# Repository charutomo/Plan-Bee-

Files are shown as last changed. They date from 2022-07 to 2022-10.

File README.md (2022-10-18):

# Plan-Bee-
**Hand crank Emergency Power Bank**

**Welcome!** :wave:

## Introduction
<h3 align="center">Plan Bee</h3>
<div align="center">
  <a href="https://github.com/charutomo/Plan-Bee-">
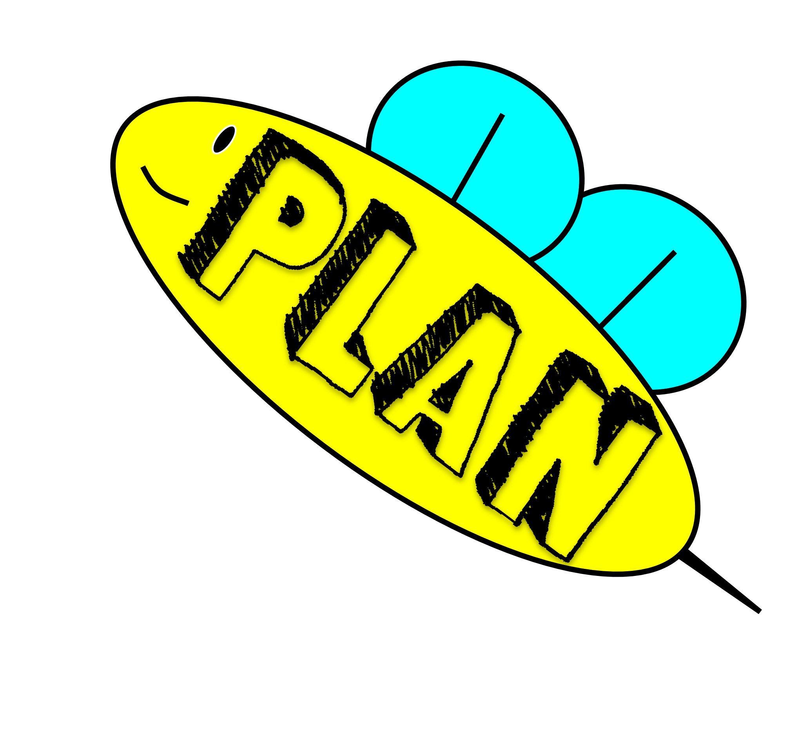
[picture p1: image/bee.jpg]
bee
    
  </a>
</div>

[Andy](https://github.com/Andypek921), Jia Woei, [Jinghui](https://github.com/jhlow5), 
[Chermaine](https://github.com/chermainegoh) and [Charissa](https://github.com/charutomo) 
are part of Plan Bee and we are making a prototype of an emergency hand crank power bank 
in fulfilment of the course PS5888: Making and Tinkering. In this particular repository, 
it would consists the C & C++ codes of our functions in our power bank
for Arduino Uno and ESP32-WROOM-32D respectively. More Information can be found in our [blog](https://blogs.ntu.edu.sg/ps5888-2022-g11/).

<br>

## Content Of Repository 
Listed below are the current codes for `Plan Bee `: 

### Hyperlinks to the respective folders
Click to view the table of content
<br>
<details>
	<summary>Table of Content</summary>

* [README.MD](https://github.com/charutomo/Plan-Bee-/blob/main/README.md)

* [License](https://github.com/charutomo/Plan-Bee-/blob/main/LICENSE)

* [Arduino Uno](https://github.com/charutomo/Plan-Bee-/blob/main/for%20Arduino)
	* [LED](https://github.com/charutomo/Plan-Bee-/blob/main/for%20Arduino/LED/LED.ino)

	* [Current, Voltage and Power Monitor](https://github.com/charutomo/Plan-Bee-/blob/main/for%20Arduino/INA3221_for_arduino_testing/INA3221_for_arduino_testing.ino)

* [ESP32-WROOM-32D](https://github.com/charutomo/Plan-Bee-/blob/main/for%20ESP32)
	* [for ILI9341](https://github.com/charutomo/Plan-Bee-/blob/main/for%20ESP32/for%20ILI9341)

	* [for SSH1106](https://github.com/charutomo/Plan-Bee-/blob/main/for%20ESP32/for%20SH1106/SH1106)
	
	* [for SSD1306](https://github.com/charutomo/Plan-Bee-/blob/main/for%20ESP32/for%20SSD1306/INA3221_works)

* [Modified Libraries](https://github.com/charutomo/Plan-Bee-/tree/main/modified%20libraries)
	* [Adafruit_ILI9341](https://github.com/charutomo/Plan-Bee-/tree/main/modified%20libraries/Adafruit_ILI9341)

	* [TFT_eSPI](https://github.com/charutomo/Plan-Bee-/tree/main/modified%20libraries/TFT_eSPI)

* [image](https://github.com/charutomo/Plan-Bee-/blob/main/image)

</details>

### Structure of repository

The structure of `Plan Bee ` repository is as such:

```
Plan Bee 
│	README.md
│	LICENSE
│
├───	PCB Design
│	├─── PCB Main V1
│	├─── PCB Main V2
│	└─── PCB Main V3
│
├───	For Arduino
│	├─── INA226 for arduino uno
│	├─── INA3221 for arduino uno
│	├─── LED
│	└─── Voltage and Current sensor using ACS712 and potentiometer
│
├─── For ESP32
│	├─── for ILI9341
│	│    ├─── ILI9341_INA226
│	│    ├─── ILI9341_INA3221
│	│    ├─── graphictestILI9341
│	│    ├─── printextILI9341
│	│    └─── README.md
│	│
│	├─── for SH1106
│	│    ├─── SH1106 (using INA3221 and general use)
│	│    ├─── SH1106_forUsers (using INA3221 and for users)
│	│    └─── README.md
│	│
│	├─── for SSD1306
│	│    └───  INA3221_works
│	│
│	└─── intermediate
│	     ├─── Temperature
│	     └─── switch
│
├─── image
│	├─── Plan Bee Logo (ALIVE).png
│	├─── Plan Bee Logo (DEAD).png
│	├─── bee.jpg
│	└─── pinout.jpg
│
├─── modified libraries
│	├─── Adafruit_ILI9341
│	└─── TFT_eSPI
│

```

<br>

## Libraries
These are libraries imported:

### Current and Voltage Sensor
* [BeastDevices INA3221](https://github.com/beast-devices/Arduino-INA3221)
* [INA226_WE](https://github.com/wollewald/INA226_WE)

### Display Screen
* [Adafruit SSD1306](https://github.com/adafruit/Adafruit_SSD1306)
* [Adafruit ILI9341](https://github.com/adafruit/Adafruit_ILI9341)
* [TFT_eSPI](https://github.com/Bodmer/TFT_eSPI)
* [ESP32-SH1106-OLED](https://github.com/nhatuan84/esp32-sh1106-oled)
* [Modified Libraries](https://github.com/charutomo/Plan-Bee-/tree/main/modified%20libraries/)

### Datetime
* [NTPClient](https://github.com/barsrb/NTPClient)
* [ESP32Time](https://github.com/fbiego/ESP32Time)

### Temperature Sensor
* [DallasTemperature](https://github.com/vlast3k/Arduino-libraries/tree/master/DallasTemperature)

### Encoder
* [Ai Esp32 Rotary Encoder](https://github.com/igorantolic/ai-esp32-rotary-encoder)

<br>

## Components
Currently, we use the following items for the functions: 
|Items			| Model No. 1	| Model No. 2 | Model No. 3|
| :---:	|:---:	 	|:---: |:---:  |
|Current, Voltage Sensor| INA3221	 	| INA226	  | -		 |
|Display Screen		| SSD1306	 	| SSH1106	  | ILI9341	 |
|Temperature Sensor	| DS18B20	 	|	-	  |	-	 |
|Encoder			| HW040	 	|	-	  |	-	 |
|Relay			|SRD-05VDC-SL-C	| 	-	  |	-	 |
|Button			|Tactile Push Button|	-	  |	-	 |

<br>

## Getting started

1. Clone this repository into your working station, key in the following command in CMD(Windows) or Terminal(Mac or Linux). 

For Windows/Mac, to save the repository content into a folder in Desktop: 

```
cd Desktop
```

Followed by 

```
git clone https://github.com/charutomo/Plan-Bee-
```

For Linux, to save the repository content into a folder in Desktop: 

```
$ ls Desktop
```

Followed by 

```
$ git clone https://github.com/charutomo/Plan-Bee-
```

2. Install Arduino IDE(if you haven't) and download the [libraries](#libraries) to have the full features.

3. You can start upload code from the repository to test out.

<br>

## Acknowledgement
Special thanks to Tony and Qi Jie for their guidance throughout the whole project of `Plan Bee`.

<br>

## Further enquiries
Please direct your enquiries to planbee9555@gmail.com or under the issues section.

<br>

Thank you for your support! :blush:

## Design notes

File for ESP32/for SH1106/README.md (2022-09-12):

# ESP32 Pinout connected to SSH1106
<br/>

## Pinout
<h3 align="center">Pinout For ESP32-WROOM-32D</h3>
<div align="center">
  <a href="https://github.com/charutomo/Plan-Bee-">
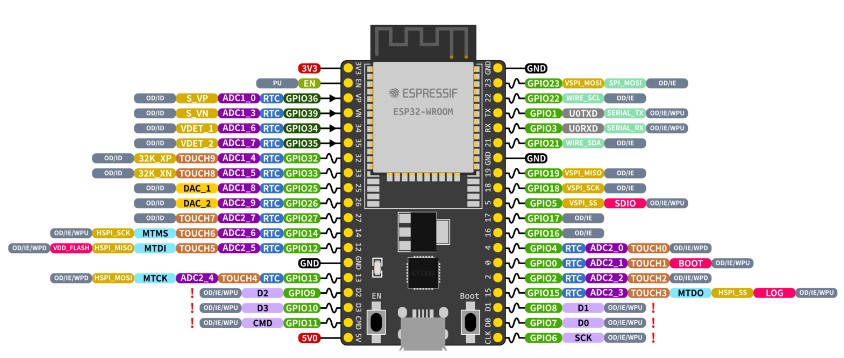
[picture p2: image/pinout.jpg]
pinout
    
  </a>
</div>
Above shows the pinout of ESP32-WROOM-32D.
<br/>

## List of Pins
Listed below are the current pins occupied for `Plan Bee`: 
<br/>
SSH1106
<br/>
|SSH1106		|Type of Pin on ESP32 	|
|:---:|:---:	 	|
|GND		|GND 		|
|VCC		|3v3	 	 |
|SCL		|22	 		|
|SDA		|21			|
<br/>
This is for the 1.3 inch ILI9341 Display.
<br/>
<br/>

Temperature Sensor DS18B20
<br/>
|DS18B20		|Type of Pin on ESP32 |
| :---:	|:---:		 	|
|VCC			|5V	 	 	 |
|DQ			|0		 		 |
|GND			|GND 		 	|
<br/>

INA3221 Current and Voltage Sensor
<br/>
|INA3221		|Type of Pin on ESP32 |
| :---:|:---:		 |
|VCC			|3v3	 	 |
|GND			|GND 		 |
|SCL			|22	 		 |
|SDA			|21			 |
<br/>

INA226 Current and Voltage Sensor
<br/>
|INA226		|Type of Pin on ESP32 |
| :---:|:---:		 |
|VCC			|3v3	 	 |
|GND			|GND 		 |
|SDA			|22	 		 |
|SCL			|21			 |
|ALERT			|25			 |
<br/>

Button
<br/>
|Button		|Type of Pin on ESP32 |
| :---:|:---:		 |
|VCC					|3v3	 	 |
|Digital Pin			|4 		 |
<br/>

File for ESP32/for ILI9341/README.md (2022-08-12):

# ESP32 Pinout for Plan Bee

## Pinout
<h3 align="center">Plan Bee</h3>
<div align="center">
  <a href="https://github.com/charutomo/Plan-Bee-">
    pinout
  </a>
</div>
Above shows the pinout of ESP32-WROOM-32D.

## List of Pins
Listed below are the current pins occupied for `Plan Bee`: 

### ILI9341 Display
|ILI9341 Display	|Type of Pin on ESP32 |
| :---:	|:---:		 |
|MISO			|12	 	 |
|LED			|3v3		 |
|SCK			|32	 		 |
|MOSI			|33			 |
|DC			|26	 		 |
|RESET		|25			 |
|CS			|27			 |
|GND			|GND 		 |
|VCC			|3v3	 	 |

This is for the 2.4 inch ILI9341 Display.

### SSH1106
|SSH1106		|Type of Pin on ESP32 	|
|:---:|:---:	 	|
|GND		|GND 		|
|VCC		|3v3	 	 |
|SCL		|22	 		|
|SDA		|21			|

This is for the 1.3 inch ILI9341 Display.

### SSD1306
|SSD1306		|Type of Pin on ESP32	 |
|:---:	|:---:	 	 |
|GND		|GND 		 |
|VCC		|3v3	 	 |
|D0		|32	 		 |
|D1		|33			 |
|RESET	|25		 	 |
|DC		|26			 |
|CS		|27			 |

This is for the 0.96 inch ILI9341 Display.

### Temperature Sensor DS18B20
|DS18B20		|Type of Pin on ESP32 |
| :---:	|:---:	 |
|VCC			|5V	 	 |
|DQ			|0	 |
|GND			|GND 	 |

### INA3221 Current and Voltage Sensor
|INA3221		|Type of Pin on ESP32 |
| :---:|:---:		 |
|VCC			|3v3	 	 |
|GND			|GND 		 |
|SCL			|22	 		 |
|SDA			|21			 |

### INA226 Current and Voltage Sensor
|INA226		|Type of Pin on ESP32 |
| :---:	|:---:		 |
|VCC			|3v3	 	 |
|GND			|GND 		 |
|SDA			|21			 |
|SCL			|22	 		 |
|ALERT		|25 *intercept	 |

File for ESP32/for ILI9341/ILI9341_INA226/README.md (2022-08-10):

# ESP32 Pinout connected to ILI9341 & INA226
<br/>

## Pinout
<h3 align="center">Pinout For ESP32-WROOM-32D</h3>
<div align="center">
  <a href="https://github.com/charutomo/Plan-Bee-">
    pinout
  </a>
</div>
Above shows the pinout of ESP32-WROOM-32D.
<br/>

## List of Pins
Listed below are the current pins occupied for `Plan Bee`: 
<br/>
ILI9341 Display
<br/>
|ILI9341 Display	|Type of Pin on ESP32 |
| :---:	|:---:		 |
|MISO			|12	 	 |
|LED			|3v3		 |
|SCK			|32	 		 |
|MOSI			|33			 |
|DC			|26	 		 |
|RESET		|25			 |
|CS			|27			 |
|GND			|GND 		 |
|VCC			|3v3	 	 |
<br/>
This is for the 2.4 inch ILI9341 Display.
<br/>
<br/>

Temperature Sensor DS18B20
<br/>
|DS18B20		|Type of Pin on ESP32 |
| :---:	|:---:		 	|
|VCC			|5V	 	 	 |
|DQ			|0		 		 |
|GND			|GND 		 	|
<br/>

INA226 Current and Voltage Sensor
<br/>
|INA226		|Type of Pin on ESP32 |
| :---:|:---:		 |
|VCC			|3v3	 	 |
|GND			|GND 		 |
|SDA			|21	 		 |
|SCL			|22			 |
|ALERT			|18			 |
<br/>

SRD-05VDC-SL-C Relay
<br/>
|SRD-05VDC-SL-C		|Type of Pin on ESP32 |
| :---:	|:---:		 |
|VCC				|3v3	 	 |
|IN1				|2			 |
|GND				|GND 		 |
<br/>

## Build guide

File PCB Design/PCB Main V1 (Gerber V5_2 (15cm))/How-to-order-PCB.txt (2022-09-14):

How to Order PCB

Please refer to:
https://docs.easyeda.com/en/PCB/Order-PCB

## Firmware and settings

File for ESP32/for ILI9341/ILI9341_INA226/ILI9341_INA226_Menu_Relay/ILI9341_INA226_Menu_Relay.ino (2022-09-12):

#include "SPI.h"
#include "Adafruit_ILI9341.h"
#include "Bee.h"
#include "AiEsp32RotaryEncoder.h"
#include "Arduino.h"
#include <Wire.h>
#include <INA226_WE.h>
#include <SPI.h>
#include <DallasTemperature.h>

#define TFT_CLK    32 
#define TFT_MOSI   33
#define TFT_MISO   12 
#define TFT_CS     27 
#define TFT_DC     26 
#define TFT_RST    25 
#define PRINT_DEC_POINTS  3  
#define SENSOR_PIN  0 
#define ROTARY_ENCODER_A_PIN 14
#define ROTARY_ENCODER_B_PIN 17
#define ROTARY_ENCODER_BUTTON_PIN 16
#define ROTARY_ENCODER_VCC_PIN - 1 
#define ROTARY_ENCODER_STEPS 4
#define RELAY_PIN1 2

float tempC; 
float tempF;
float shuntVoltage_mV = 0.0;
float loadVoltage_V = 0.0;
float busVoltage_V = 0.0;
float current_mA = 0.0;
float power_mW = 0.0; 
int menu_state = 0;
int value = 0;
int batt = 0;
int temp = 1;
int cred = 1;
int tech = 1;
float voltage[2];
bool active_state = false;

OneWire oneWire(SENSOR_PIN);
DallasTemperature DS18B20(&oneWire);
Adafruit_ILI9341 tft = Adafruit_ILI9341(TFT_CS, TFT_DC, TFT_MOSI, TFT_CLK, TFT_RST, TFT_MISO);
AiEsp32RotaryEncoder rotaryEncoder = AiEsp32RotaryEncoder(ROTARY_ENCODER_A_PIN, ROTARY_ENCODER_B_PIN, ROTARY_ENCODER_BUTTON_PIN, ROTARY_ENCODER_VCC_PIN, ROTARY_ENCODER_STEPS);
INA226_WE ina226batt = INA226_WE(0x40); 

void IRAM_ATTR readEncoderISR() {
  rotaryEncoder.readEncoder_ISR();
}

void setup() {
  //initialize rotary encoder
  rotaryEncoder.begin();
  rotaryEncoder.setup(readEncoderISR);
  //set boundaries and if values should cycle or not
  //in this example we will set possible values between 0 and 1000;
  bool circleValues = false;
  rotaryEncoder.setBoundaries(0, 1000, circleValues); //minValue, maxValue, circleValues true|false (when max go to min and vice versa)
  rotaryEncoder.setAcceleration(250); 

  //initalise digital pin as an output
  pinMode(RELAY_PIN1, OUTPUT);

  Serial.begin(115200);
  
  tft.begin();
  DS18B20.begin();
  Wire.begin();
  tft.fillScreen(ILI9341_BLACK);
  tft.setRotation(0);
  tft.drawRGBBitmap(0, 0, Plan_Bee_Logo_ALIVE, BEE_WIDTH,BEE_HEIGHT);
  delay(1000);
  
  ina226batt.init();
  ina226batt.setAverage(AVERAGE_128); 
  ina226batt.setConversionTime(CONV_TIME_8244); 
  ina226batt.setMeasureMode(TRIGGERED); 
  ina226batt.setCurrentRange(MA_800); 
  ina226batt.setCorrectionFactor(0.72); 
  menu();

  Serial.println(active_state);
}

void loop() {
  if (active_state == true){
    if (rotaryEncoder.encoderChanged() && menu_state < 5) {
      value = rotaryEncoder.readEncoder();
      Serial.println(value);
      if (value % 4 == 0) {
        menu_state = 1;
        batt = 1;
      } else if (value % 4 == 1) {
        menu_state = 2;
        temp = 1;
      } else if (value % 4 == 2) {
        menu_state = 3;
        cred = 1;
      }
      else if (value % 4 == 3) {
        menu_state = 4;
        tech = 1;
      }
      changemenu();
    }
    if (rotaryEncoder.isEncoderButtonClicked()) {
      if (menu_state >= 5){
        menu_state = 0;
      } else if (value % 4 == 0) { 
        menu_state = 7;
      } else if (value % 4 == 1) {
        menu_state = 8;
      } else if (value % 4 == 2) {
        menu_state = 9;
      } 
      else if (value % 4 == 3) {
        menu_state = 10;
      } 
      changemenu();
    }
    if (menu_state>5){
      changemenu();
      delay(1000);
    }
  }   
  else if(active_state == false){
    for (int i = 0; i < 7000; i++){ 
      //Serial.println(i);
      if (rotaryEncoder.isEncoderButtonClicked()) {
        active_state = true;
        menu1();
      }
    }
    Serial.println(active_state);
    Serial.print("Start: ");
    Serial.println(millis());
    ina226batt.startSingleMeasurement();
    ina226batt.readAndClearFlags();
    voltage[0] = ina226batt.getBusVoltage_V(); 
    relay(voltage[0]);
    Serial.println(voltage[0]);
    Serial.print("End: ");
    Serial.println(millis());
  }
}

void changemenu() {
  /* Menu values
  0: main menu without any selector
  1: main menu with selector on Battery Info
  2: main menu with selector on Temperature
  3: main menu with selector on Credits
  4: main menu with selector on Tech Support

  7: Battery Info Page
  8: Temperature Page 
  9: Credits Page
  10: Tech Support Page
  */
  switch (menu_state) {
  case 0:
    menu();
    break;
  case 1:
    menu1();
    break;
  case 2:
    menu2();
    break;
  case 3:
    menu3();
    break;
  case 4:
    menu4();
    break;
  case 7:
    showbattery();
    break;
  case 8:
    showtemp();
    break;
  case 9:
    credits();
    break;
  case 10:
    techsupport();
    break;
  }
}

// menu with no selector
void menu() {
  tft.fillScreen(ILI9341_BLACK);
  tft.setRotation(0);
  tft.setTextSize(2);
  tft.setTextColor(ILI9341_YELLOW);
  tft.setCursor(70, 40);
  tft.println("Battery Info");
  tft.setCursor(70, 70);
  tft.println("Temperature");
  tft.setCursor(70, 100);
  tft.println("Credits");
  tft.setCursor(70, 130);
  tft.println("Tech Support");
  active_state = false;
  Serial.println("false");
}

// menu with selector on 1
void menu1() {
  tft.fillRect(40,40,30,130, ILI9341_BLACK);
  tft.setCursor(40, 40);
  tft.print("->");
}

// menu with selector on 2
void menu2() {
  tft.fillRect(40,40,30,130, ILI9341_BLACK);
  tft.setCursor(40, 70);
  tft.print("->");
}

// menu with selector on 3
void menu3() {
  tft.fillRect(40,40,30,130, ILI9341_BLACK);
  tft.setCursor(40, 100);
  tft.print("->");
}

// menu with selector on 4
void menu4(){
  tft.fillRect(40,40,30,130, ILI9341_BLACK);
  tft.setCursor(40, 130);
  tft.print("->");
}

// show the battery value
void showbattery(void) {
  if (batt ==1){
    refreshorig();
    batt = 0;
  }
  else {
    refreshbatt();
  }
  float current[2]; //no. of channels
  float voltage[2];
  ina226batt.startSingleMeasurement();
  ina226batt.readAndClearFlags();
  current[0] = ina226batt.getCurrent_mA();
  voltage[0] = ina226batt.getBusVoltage_V();
  float power0 = ina226batt.getBusPower();
  float battpercent = ((voltage[0]-3.4)/(4.2-3.4))*100;
  offsettext(0,3);
  tft.println("Battery");
  offsettext(40,2);
  tft.print("Current:");
  tft.println(current[0], PRINT_DEC_POINTS);
  offsetunits(40,2);
  tft.print("mA, ");
  offsettext(70,2);
  tft.print("Voltage:");
  tft.println(voltage[0], PRINT_DEC_POINTS);
  offsetunits(70,2);
  tft.print("V, ");
  offsettext(100,2);
  tft.print("Power: "); 
  tft.println(power0);
  offsetunits(100,2);
  tft.print("mW");
  offsettext(130,2);
  tft.println("Battery Percentage:");
  offsettext(160,2);
  tft.print(battpercent);
  offsetunits(160,2);
  tft.println("%");
}

// show the temperature
void showtemp(void) {
  if (temp ==1){
    refreshorig();
    temp = 0;
  }
  else{
    refreshtemp();
  }
  offsettext(0,3);
  tft.println("Temperature");
  tft.println();
  DS18B20.requestTemperatures();       
  tempC = DS18B20.getTempCByIndex(0);  
  tempF = tempC * 9 / 5 + 32;
  offsetdegrees(30);
  offsettext(40,2);
  tft.print(tempC);
  tft.println(" C");
  offsetdegrees(60);
  offsettext(70,2);
  tft.print(tempF);
  tft.println(" F");

  delay(1000);
}

// show the credits
void credits(void) {
  if (cred == 1){
    refreshorig();
    cred = 0;
  }
  offsettext(0,3);
  tft.println("Credits");
  tft.println();
  offsettext(30,2);
  tft.println("Group Members:");
  offsettext(60,2);
  tft.println("Andy,Jia Woei,Jing Hui,");
  offsettext(90,2);
  tft.println("Chermaine and Charissa");
  tft.println();
  offsettext(120,2);
  tft.println("With thanks to Tony");
  offsettext(150,2);
  tft.println("and Qi Jie");

  delay(1000);
}

//show tech support information
void techsupport(void){
  if (tech == 1){
    refreshorig();
    tech = 0;
  }
  offsettext(0,3);
  tft.println("Tech Support");
  offsettext(40,2);
  tft.println("Email Address:");
  offsettext(70,2);
  tft.println("planbee9555@gmail.com");

  delay(1000);
}

void offsettext(int y, int font){
  /*
   * Function: offsetdegree
   * ----------------
   * Set cursor to (40,y) which indent the screen and set text size accordingly to the input font
   * 
   * y: y-axis value to be input for printing text
   * font: font size of the text to be printed on display
   */
  tft.setCursor(40, y);
  tft.setTextColor(ILI9341_YELLOW);
  tft.setTextSize(font);
}

void offsetdegrees(int y){
  /*
   * Function: offsetdegrees
   * ----------------
   * Set cursor and indent the screen to show the degree symbol
   * 
   * y: y-axis value to be input for the degrees symbol
   * 
   */
  tft.setCursor(100, y);
  tft.setTextColor(ILI9341_YELLOW);
  tft.setTextSize(1);
  tft.println("o");
}

void offsetunits(int y, int font){
  /*
   * Function: offsetunits
   * ----------------
   * Set cursor and indent the units to x = 240
   * 
   * y: y-axis value to be input for the units symbol
   * font: font size of the text to be printed on display
   * 
   */
   tft.setCursor(240, y);
   tft.setTextColor(ILI9341_YELLOW);
   tft.setTextSize(font);
   
}

void refreshorig(void){
  /*
   * Function: refreshorig
   * ----------------
   * Fills a blackbox space to cover the menu screen for refreshing page 
   * 
   */
  tft.fillRect(40,40,200,120,ILI9341_BLACK);
}

void refreshbatt(void){
  /*
   * Function: refreshbatt
   * ----------------
   * Fills a blackbox space to cover the old battery values
   * for refreshing page on battery screen before showing new values
   * 
   */
  tft.fillRect(135,40,80,60,ILI9341_BLACK);
  tft.fillRect(110,100,100,20,ILI9341_BLACK);
  tft.fillRect(40,160,90,30,ILI9341_BLACK);
}

void refreshtemp(void){
  /*
   * Function: refreshtemp
   * ----------------
   * Fills a blackbox space to cover the old temperature values for refreshing page
   * on temperature screen before showing new values
   * 
   */
  tft.fillRect(40,30,60,80,ILI9341_BLACK);
}

void relay(float avgvolt) {
  /*
   * Function: relay
   * ----------------
   * Activates relay with normally closed mode .
   * If any given voltage of battery is above 4.2 volts, it switches off to prevent overcharging of the battery.
   * Otherwise, it will continuously be on.
   * 
   */
  if (avgvolt >= 4.2) {
    digitalWrite(RELAY_PIN1, HIGH); 
  }
  else {
    digitalWrite(RELAY_PIN1, LOW);
  }
}

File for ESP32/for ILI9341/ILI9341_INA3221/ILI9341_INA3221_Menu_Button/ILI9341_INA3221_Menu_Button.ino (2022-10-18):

#include "SPI.h"
#include <TFT_eSPI.h>
#include "Arduino.h"
#include "Bee.h"
#include <Wire.h>
#include <Beastdevices_INA3221.h>
#include <SPI.h>
#include <OneWire.h>
#include <DallasTemperature.h>
#include <WiFi.h>
#include <NTPClient.h>
#include <WiFiUdp.h>
#include <ESP32Time.h>

#define TFT_SCLK 32
#define TFT_MOSI 33
#define TFT_MISO 12
#define TFT_CS   27
#define TFT_DC 26
#define TFT_RST 25
#define PRINT_DEC_POINTS  3  
#define SENSOR_PIN  0
#define BUTTON_PIN 4 // GPIO4 pin connected to button
//#define TFT_WIDTH 240
//#define TFT_HEIGHT  320

float current1;
float voltage1;
float power1;
float battery1;
float energy1;
float current2;
float voltage2;
float power2;
float energy3;
float current3;
float voltage3;
float power3;
float energy2;
float tempC; 
float tempF;
float currentarray1[10];
float voltagearray1[10];
float powerarray1[10];
float currentarray2[10];
float voltagearray2[10];
float powerarray2[10];
float currentarray3[10];
float voltagearray3[10];
float powerarray3[10];
int clicknum;
int lastState = HIGH;
int currentState;
int batt = 1;
int temp = 1;
int cred = 1;
int tech = 1;
int cust = 1;
int numloop = 0;
unsigned long drawTime = 0;
// Replace with your network credentials
const char* ssid     = "SSID";
const char* password = "Password";
char *dayarray[]= {"Monday", "Tuesday", "Wednesday", "Thursday", "Friday", "Saturday", "Sunday"};

Beastdevices_INA3221 ina3221(INA3221_ADDR40_GND); 

OneWire oneWire(SENSOR_PIN);
DallasTemperature DS18B20(&oneWire);
TFT_eSPI tft = TFT_eSPI(); 
WiFiUDP ntpUDP;
NTPClient timeClient(ntpUDP);
ESP32Time rtc(0);

void setup() {
  Serial.begin(115200);
  
  // initialise the screen
  tft.begin();
  tft.fillScreen(ILI9341_WHITE);
  tft.setFreeFont(FF33);
  DS18B20.begin();

  //draw the bee logo
  int x = random(tft.width()  - BEE_WIDTH);
  int y = random(tft.height() - BEE_HEIGHT);
  //using the drawXBitmap function, bee_logo is in the header folder, Bee.h
  tft.drawXBitmap(x, y, bee_logo, BEE_WIDTH,BEE_HEIGHT,TFT_BLACK,TFT_WHITE); // monochrome, white background
  delay(1000);

  // initialise the NTPClient
  //wifiConnect();
  //custom page ro show the name of the owner of the power bank and datetime
  rtc.setTime(00, 40, 16, 18, 10, 2022);
  
  // initialise INA3221
  ina3221.begin();
  ina3221.reset();
  ina3221.setShuntRes(100, 100, 100);
  tft.fillScreen(ILI9341_BLACK);

}

void loop() {
  currentState = digitalRead(BUTTON_PIN);
  int index = clicknum%7;
  ifClick();
  Serial.println(currentState);
  switch(index){
    case 0:
      showcustom();
      break;
    case 1:
      showbattery();
      break;
    case 2:
      showinput();
      break;
    case 3:
      showoutput();
      break;
    case 4:
      showtemp();
      break;
    case 5:
      credits();
      break;
    case 6:
      techsupport();
      break;
    
  }
  lastState = currentState;
}

void ifClick(void){
 if (lastState == LOW && currentState == HIGH){
    clicknum++;
    cred = 1;
    tech = 1;
    batt = 1;
    temp = 1;
    cust = 1;
    Serial.print(clicknum);
    }
}

void wifiConnect(void){
  Serial.print("Connecting to ");
  Serial.println(ssid);
  WiFi.begin(ssid, password);
  while (WiFi.status() != WL_CONNECTED) {
    delay(500);
    Serial.print(".");
  }
  // Print local IP address and start web server
  Serial.println("");
  Serial.println("WiFi connected.");
  Serial.println("IP address: ");
  Serial.println(WiFi.localIP());

  // Initialize a NTPClient to get time
//  timeClient.begin();
  // Set offset time in seconds to adjust for your timezone, for example:
  // GMT +1 = 3600
  // GMT +8 = 28800
  // GMT -1 = -3600
  // GMT 0 = 0
//  timeClient.setTimeOffset(0); 
}

void showcustom(void){
  if (cust ==1){
    tft.fillScreen(ILI9341_BLACK);
    cust = 0;
  }
  offsettext(40);
  tft.println("Hello Name!");  

  //using library ESP32Time
  offsettext(120);
  tft.setTextPadding(100);
  tft.print(rtc.getDate(true));
  
  offsettext(150);
  tft.print("Time Now - ");
  tft.setTextPadding(100);
  tft.drawString(rtc.getTime(),160,137);

  //for NTPClient
//  while(!timeClient.update()) {
//    timeClient.forceUpdate();
//  }
//
//  offsettext(120);
//  tft.print("Date - ");
//  tft.print(timeClient.getDay());
//  tft.print(" / ");
//  tft.print(timeClient.getMonth());
//  tft.print(" / ");
//  tft.print(timeClient.getYear());
//  
//  offsettext(150);
//  tft.print("Day - ");
//  tft.print(dayarray[timeClient.getDayOfWeek()-1]);
//  
//  offsettext(180);
//  tft.print("Time Now - ");
//  tft.print(timeClient.getFormattedTime());
}

// show the battery value
void showbattery(void) {
  if (batt ==1){
    tft.fillScreen(ILI9341_BLACK);
    batt = 0;
  }
  int index = numloop%10;
  currentarray1[index] = ina3221.getCurrent(INA3221_CH1);
  voltagearray1[index] = ina3221.getVoltage(INA3221_CH1);
  numloop++;
  if (numloop<10){
      current1 = avgvalue(currentarray1,numloop);
      voltage1 = avgvalue(voltagearray1,numloop);
      power1 = avgvalue(powerarr(currentarray1,voltagearray1),numloop);
      energy1 = energy(powerarr(currentarray1,voltagearray1));
      battery1 = battpercent(avgvalue(voltagearray1,numloop));
  }
  else{
      current1 = avgvalue(currentarray1,10);
      voltage1 = avgvalue(voltagearray1,10);
      power1 = avgvalue(powerarr(currentarray1,voltagearray1),10);
      energy1 = energy(powerarr(currentarray1,voltagearray1));
      battery1 = battpercent(avgvalue(voltagearray1,10));
  }
  if (numloop%10 == 0){
    tft.setRotation(0);
    offsettext(20);
    tft.println("Battery");
    
    offsettext(60);
    tft.print("Current:");
    tft.setTextPadding(100);
    tft.drawFloat(current1, 3, 150, 47);
    tft.setCursor(230, 60);
    tft.println("A");
    
    offsettext(100);
    tft.print("Voltage:");
    tft.setTextPadding(100);
    tft.drawFloat(voltage1, 3, 150, 83);
    tft.setCursor(230, 100);
    tft.print("V");
    
    offsettext(140);
    tft.print("Power:");
    tft.setTextPadding(100);
    tft.drawFloat(power1, 3, 150, 129);
    tft.setCursor(230, 140);
    tft.println("W");
  
    offsettext(180);
    tft.print("Energy:");
    //tft.print(energy1);
    tft.setTextPadding(100);
    tft.drawFloat(energy1, 3, 150, 167);
    tft.setCursor(230, 180);
    tft.println("Ws");
  
    offsettext(220);
    tft.print("Battery %:");
    tft.setTextPadding(100);
    tft.drawFloat(battery1, 2, 150, 207);
    tft.setCursor(230, 220);
    tft.println("%");
  }
}
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

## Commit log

2022-07-05 Reclassify between for arduino and esp32
    file management and incorporated logo, voltage and current readers into one ino under esp32 functions
2022-07-05 Added power function
    added in power function
2022-07-07 Add INA3221 code and edit README
    Current, voltage and power measurements can be taken in 3 channels via INA3221 sensor incorporated in codes for both arduino uno and esp32, edit README testing too
2022-07-12 Added temperature function and edit README
2022-07-15 switched the width and height values
2022-07-18 Added currently working code for ILI9341 and edit README
    Added currently working code for ILI9341 and testing README image
2022-07-21 included if else function for low battery
    included if else function for low battery
2022-07-21 ina226 code for arduino uno
    ina226 code for arduino uno
2022-07-21 Added initial menu with HW040 encoder
    Added initial menu with HW040 encoder
2022-07-22 fixed slight bug on menu code and removed the rotary_loop function
    [menuILI9341.ino]
2022-07-22 fixed accidentally deleted readEncoderISR function
    [menuILI9341.ino]
2022-07-22 beginnings of the case code
2022-07-22 move the menu change code to another function, fixed the case code
    [menuILI9341.ino]
2022-07-22 ILI9341 with bee image and ina226 for esp32
    ILI9341 with bee image and ina226 for esp32 - working in progress
2022-07-22 fixed encoder button code
    [menuILI9341.ino]
2022-07-22 changed exit screen to button click
2022-07-22 add in pinouts connecting INA226 to ESP32
    add in pinouts connecting INA226 to ESP32
2022-07-23 Added Encoder Pinout
    Added Encoder Pinout
2022-07-25 offset work and applied to credits and temperature
2022-07-25 collects 100 data points per second for current and voltage and displays
2022-07-25 sampling for 50 points for every 50ms, added avg, power, energy
    sampling for 50 points for every 50ms, added avg, power, energy
2022-07-25 add serial print to monitor numloop, arrays and avg values
    add serial print to monitor numloop, arrays and avg values
2022-07-25 changes of alert pin in ina226
    changes of alert pin in ina226
2022-07-26 CHERMAINE YOUR CONNECTION WRONG :(, I HAD TO REDO EVERYTHING
    CHERMAINE YOUR CONNECTION WRONG :(, I HAD TO REDO EVERYTHING, NEXT TIME ASK JH
    [ILI9341_INA226_Menu.ino]
2022-07-27 success in refreshing the battery page
    success in refreshing the battery page
2022-07-27 manage to do all the refresh for all the current functions
    manage to do all the refresh for all the current functions
2022-07-28 refresh battery page debug
    refresh battery page debug
2022-07-28 Added Relay function and pinout in README, edit some documentation
    Added Relay function in case of overcharge and added in relay pinout in README, edit some documentation and typos, changed the values in offsetbatt function for fixing the bug
    [ILI9341_INA226_Menu_Relay.ino, menu3221new.ino]
2022-07-29 Edit README to add Relay
2022-07-30 Added Relay function into INA3221 to be tested, edited some README for Relay and change all maximum value of voltage of 18650 battery to 4.2 instead of 4.3V
2022-08-06 Retrace the old file without relay with some changes (e.g. 4.3V to 4.2V), in the case of not using relay. Created new file for specifically adding relay.
2022-08-12 Serial print baud rate
2022-08-12 andy broke the encoder. i fixed it
    [ILI9341_INA226_Menu_Relay.ino]
2022-08-12 change encoder steps to 8 in INA3221
2022-08-12 fixed the ESP32 pinout image
2022-08-17 Revert ":clown_face: Edit INA226"
    This reverts commit 88e608d3ccfebd59fde2517b752cf53636035670.
    [ILI9341_INA226_Menu_Relay.ino]
2022-08-17 :white_check_mark: added some changes to refresh battery page
    added some changes to refresh battery page
2022-08-19 :bug: fix bug on refresh initial screen
    fix bug on refresh initial screen
    [ILI9341_INA3221_Menu_Relay.ino]
2022-09-02 shows refresh the battery screen and shows values when index is equal to 1 modulo 10, to be tested
2022-09-12 Added button on display SSH1106 and edit the power function on ILI9341 for INA3221.
2022-09-12 fix bug on refresh battery screen
    [ILI9341_INA226_Menu.ino, ILI9341_INA226_Menu_Relay.ino, menu3221new.ino]
2022-09-12 add readme button pins in SH1106
2022-09-12 Button for ILI9341
2022-09-14 added PCB designs
    [Drill_NPTH_Through.DRL, Drill_PTH_Through.DRL, Gerber_BoardOutlineLayer.GKO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]
2022-09-16 manage to make the button to work
2022-09-26 tried no flickering for battery page
2022-09-26 changed the flipped rgb values and rotated the screen
    [ILI9341_INA3221_Menu_Button.ino]
2022-09-27 added the modified library of tft_espi for ILI9341 and edit readme
    [Configuring options.txt]
2022-10-11 produces a monochrome bitmap of the bee, shifted the temperature for fahrenheits lower, made a second channel for output
2022-10-11 change to modulo 5, fix bug
    [ILI9341_INA3221_Menu_Button.ino]
2022-10-18 datetime can work without wifi now but have to reset consistently
    [ILI9341_INA3221_Menu_Button.ino]
